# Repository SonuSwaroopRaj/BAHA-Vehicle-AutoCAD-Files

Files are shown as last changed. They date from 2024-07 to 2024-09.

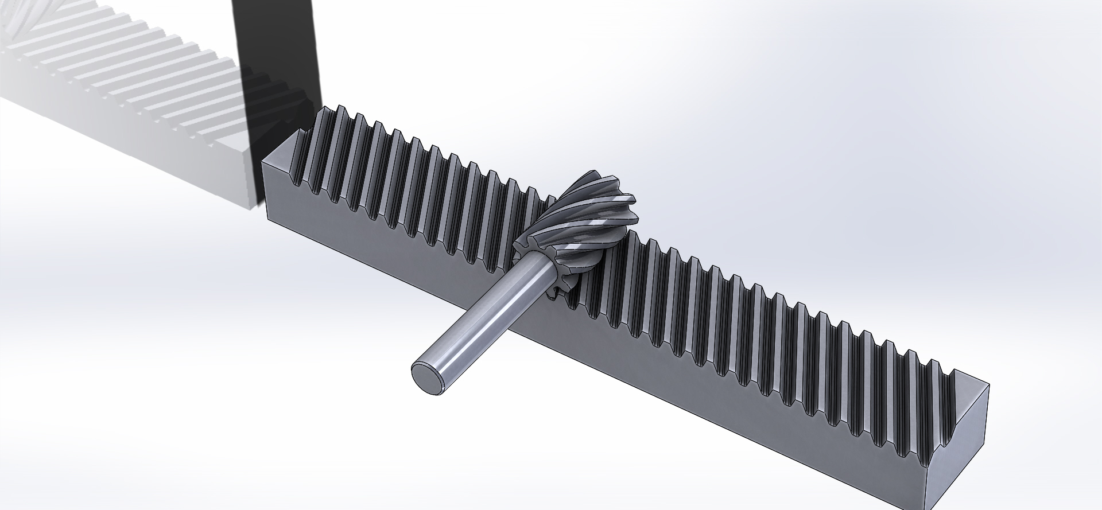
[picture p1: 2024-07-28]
RACK AND PINION DESIGN/RACK AND PINION.JPG

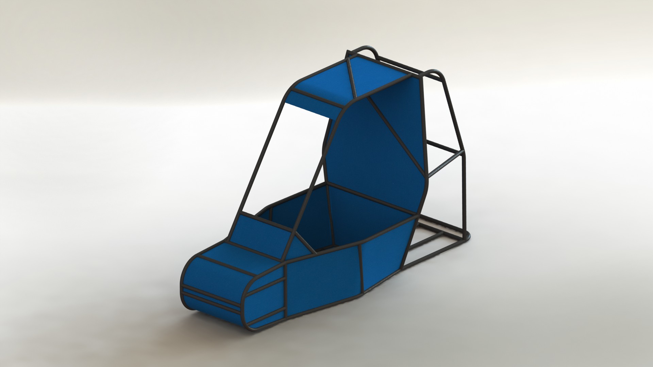
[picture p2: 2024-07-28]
ROLLCAGE CHASIS DESIGN/rendering 1420110908-19437-a36wyp.JPG

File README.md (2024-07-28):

# BAHA-Vehicle-AutoCAD-Files
This repository contains the AutoCAD files for our BAHA vehicle design. Here you'll find detailed schematics and 3D models related to the construction and design of our BAHA vehicle. The files are organized into relevant categories for easy navigation and reference. Contributions and updates to the designs are welcome.

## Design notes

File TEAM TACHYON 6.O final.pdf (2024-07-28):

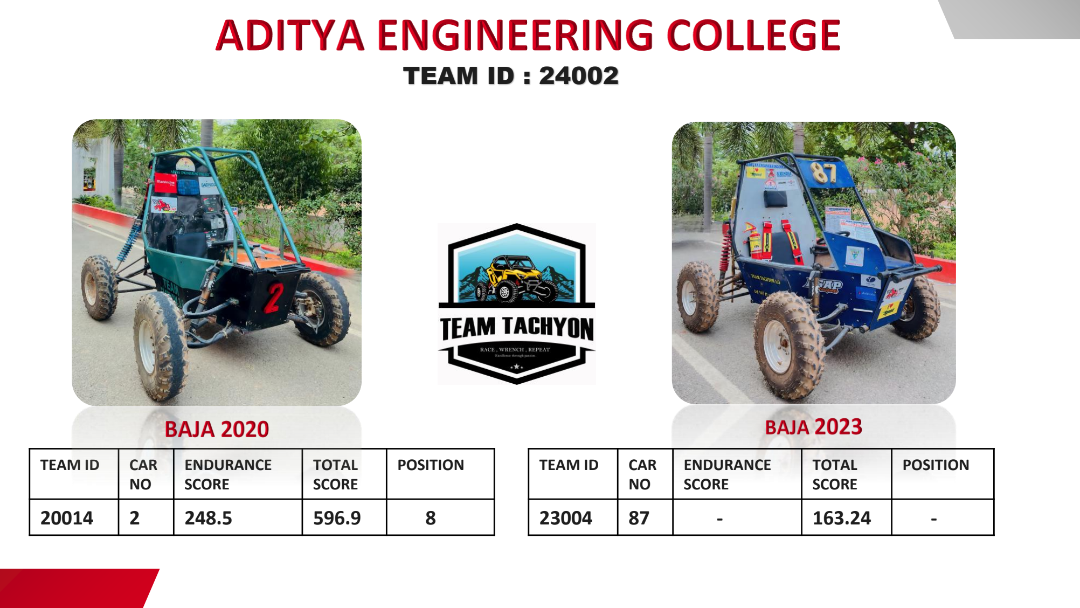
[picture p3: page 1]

TEAM ID : 24002

TEAM ID CAR
NO

ENDURANCE
SCORE

TOTAL
SCORE

POSITION

20014 | 2 | 248.5 | 596.9 | 8
TEAM ID | CAR
NO

ENDURANCE
SCORE

TOTAL
SCORE

POSITION

23004 | 87 | - | 163.24 | -

- No proper design for splash shield arrangement
- Issue in fixing the CVT and disk wheel casing
SUBSYSTEMS | FLAWS OF PREVIOUS VEHICLE | LESSONS LEARNT | IMPROVEMENT
ROLL CAGE | - | The front bracing member should have
| been the primary member but became secondary member
- No gusset between RHO & RRH
- Fbm should become
| | primary and continuous
- Should be available
| | gusset secondary according to rule book | FBM completely replaced with primary
SUSPENSION | - | Less camber control because of u arms | A-arms tend to offer more adjustability, To fine-tune the suspension settings for specific driving conditions.
- Damper position changed
to upper arm
- U- arms are replaced with A-arms
BRAKING | - | Less brake performance at rear wheels
- Occurance of brakages in hoses.
- Due to Y – split
- Because of non-
| | | metallic liners.
- Installing X- split braking circuit
- Using metallic brake liners STREERING - The ability to align the wheels not
accurtely
- No precise alignment | - Using sliding pair
TRANSMISSION | Less traction & limited torque distribution . | To required power to all 4
| | | wheels
- 4WD

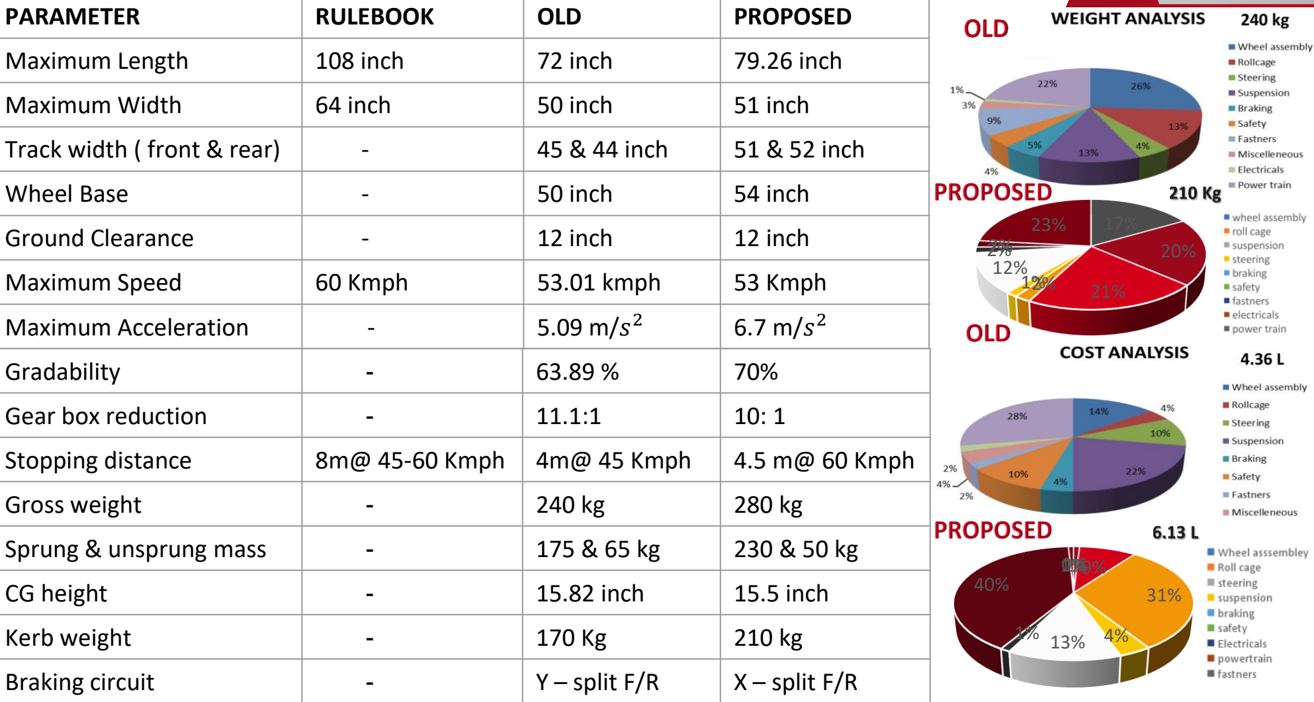
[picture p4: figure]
PARAMETER; RULEBOOK; OLD; PROPOSED; Maximum Length; 108 inch; 72 inch; 79.26 inch; Maximum Width; 64 inch; 50 inch; 51 inch; Wheel Base; 54 inch; Ground Clearance; 12 inch; Maximum Speed; 60 Kmph; 53.01 kmph; 53 Kmph; Maximum Acceleration; Gradability; Gear box reduction; Stopping distance; 8m@ 45-60 Kmph; 4m@ 45 Kmph; 4.5 m@ 60 Kmph; Gross weight; Sprung & unsprung mass; CG height; 15.82 inch; 15.5 inch; Kerb weight; Braking circuit; Y – split F/R; X – split F/R

Track width ( front & rear) | - | 45 & 44 inch | 51 & 52 inch

ROLL CAGE FEATURES

PARAMETER | VALUE | PARAMETER | ALLOWABLE VALUE | DESIGN VALUE
Total no.of joints | 94 | Maximum vehicle width | 64” | 50”
Total weld length | 5.9 m | Maximum vehicle length | 108” | 72”
Total tubing length | 50 m | Minimum firewall width of the RRH 27” above seat | > 29” | 30”
Roll cage weight | 41.3 kg
PARAMETER | OUTER DIA | THICKNESS
Primary pipes | 31.75 mm | 1.6 mm
Secondary pipes | 25.4 mm | 1.6 mm
Material used | Steel alloy with properties > 365 Mpa | AISI 4130
Vertical distance of SIM from seat (inches) | 8”- 14” | 12”
Fire wall angle | Max 20⁰ | 10⁰
Front bracing member angle | < 45 “ | 33.46”

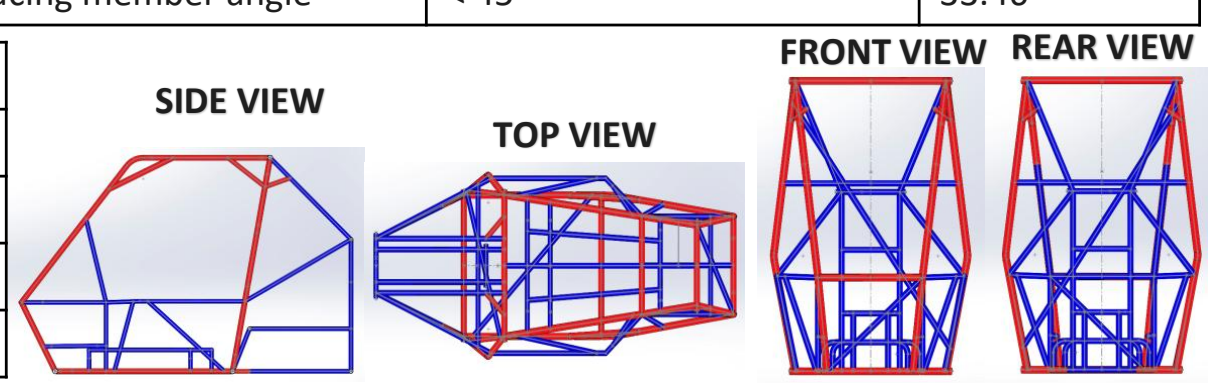
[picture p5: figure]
FRONT VIEW REAR VIEW; TOP VIEW; SIDE VIEW

PARAMETER | STD.VALUE | DESIGN VALUE
Elbows angle | 125⁰ - 140⁰ | 135⁰
Knee angle | 120⁰ - 150⁰ | 132⁰
Back angle | 8 0 - 15⁰ | 10⁰
Steering angle | 90⁰ - 65⁰ | 70⁰

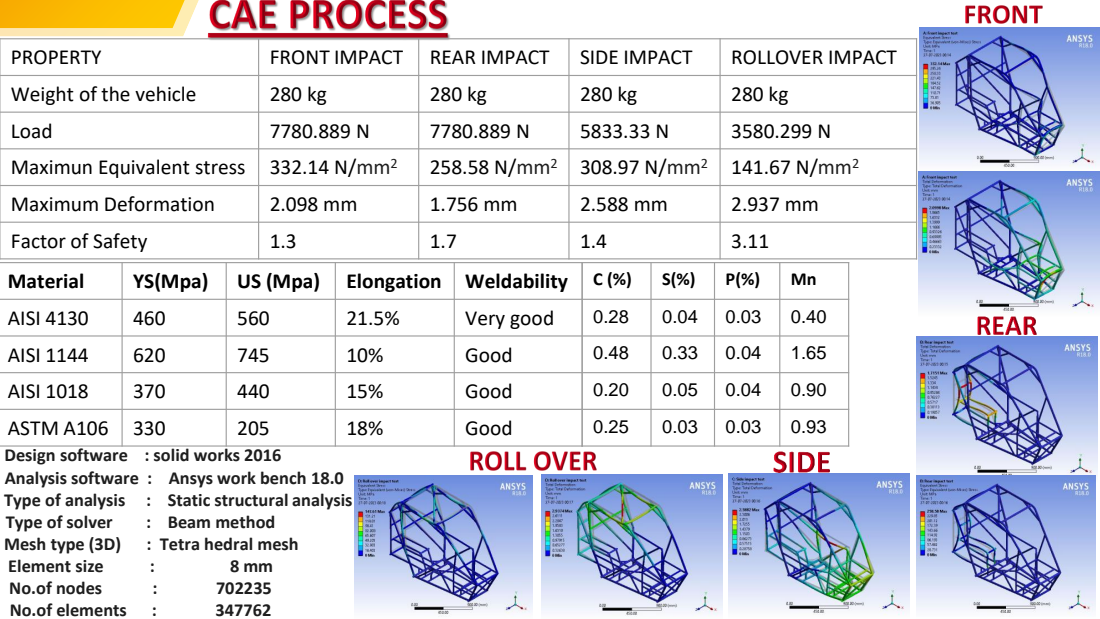
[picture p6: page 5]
Type of solver; : Beam method; Mesh type (3D); : Tetra hedral mesh; Element size; No.of nodes; No.of elements; Material; YS(Mpa); US (Mpa); Elongation; Weldability; AISI 4130; Very good; AISI 1144; Good; AISI 1018; ASTM A106; PROPERTY; FRONT IMPACT; REAR IMPACT; SIDE IMPACT; ROLLOVER IMPACT; Weight of the vehicle; Load; Maximun Equivalent stress; 332.14 N/mm²; 258.58 N/mm²; 308.97 N/mm²; 141.67 N/mm²; Maximum Deformation; Factor of Safety

Design software : solid works 2016
Analysis software : Ansys work bench 18.0
Type of analysis : Static structural analysis

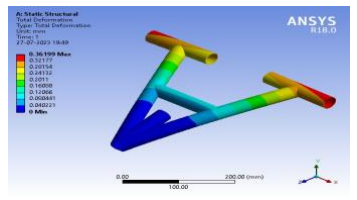
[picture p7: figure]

PARAMETER | FRONT | REAR
Suspension system | Double wish bone | H - arm
Natural frequency | 2.3 Hz | 2.5 Hz
Spring stifness | 6.942 N/mm | 16.147 N/mm
Roll rate | 19.315 Nm/deg | 22.28 Nm/deg
Suspension travel | Bump - 6” Droop - 4” | Bump – 4” Droop – 2”
Damper stroke | 5.8” | 6.2”
Damping force | 956.456 N | 1103.52 N
Damping coefficient | 2940.53 N.s/m | 3410.77 N.s/m
Damping ratio | 1.08 | 10.7
Wheel rate | 10”-6”bump,4”droop | 6” (4” bump,2” droop)
PARAMETER` | VALUE
CG height | 15.5’’
Ground clearance | 12”
Roll center height | FAW 12.52” RAW 12.49”
Motion ratios | FRONT -0.53 REAR - 1.33
Shock absorber | FOX FLOAT – 3EVOL
Helical
suspension

LINKAGE DESIGN

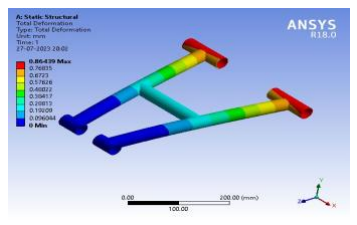
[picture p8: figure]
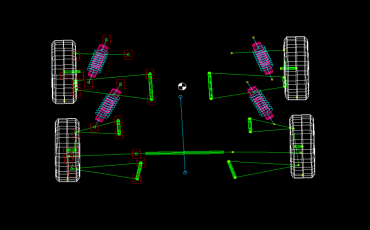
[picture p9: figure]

PARAMETER | FRONT | REAR
Camber | 2” | 2”
Caster | 2” | 0”
KPI | 8” | 0”
Scrub radius | 22 mm | 0 mm
TOE | 2 deg | 0 deg
MATERIAL | Chromium vanadium steel
Modulus of rigidity | 8000 mpa
Wire diameter | 9 mm
Eye to eye distance | 480 mm
No.of active coils | 15
Nominal diameter | 81 mm

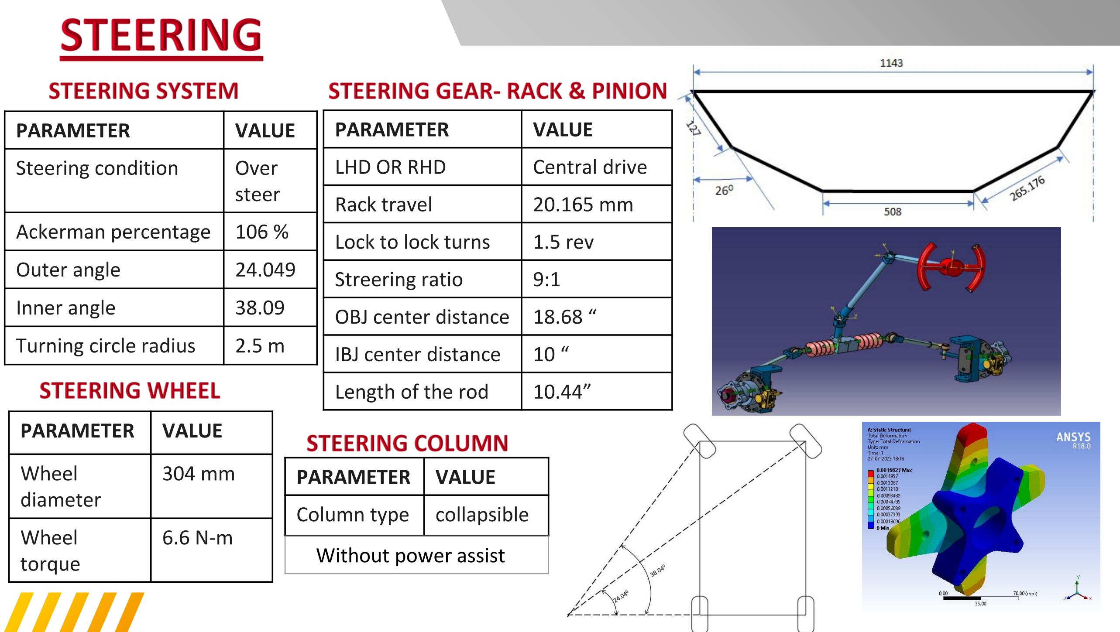
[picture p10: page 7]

PARAMETER | VALUE | PARAMETER | VALUE
Steering condition | Over steer | LHD OR RHD | Central drive
Rack travel | 20.165 mm
Lock to lock turns | 1.5 rev
Streering ratio | 9:1
OBJ center distance | 18.68 “
IBJ center distance | 10 “
Length of the rod | 10.44”
Ackerman percentage | 106 %
Outer angle | 24.049
Inner angle | 38.09
Turning circle radius | 2.5 m
PARAMETER | VALUE

Wheel
diameter

304 mm

Wheel
torque

6.6 N-m

PARAMETER | VALUE
Column type | collapsible

Without power assist

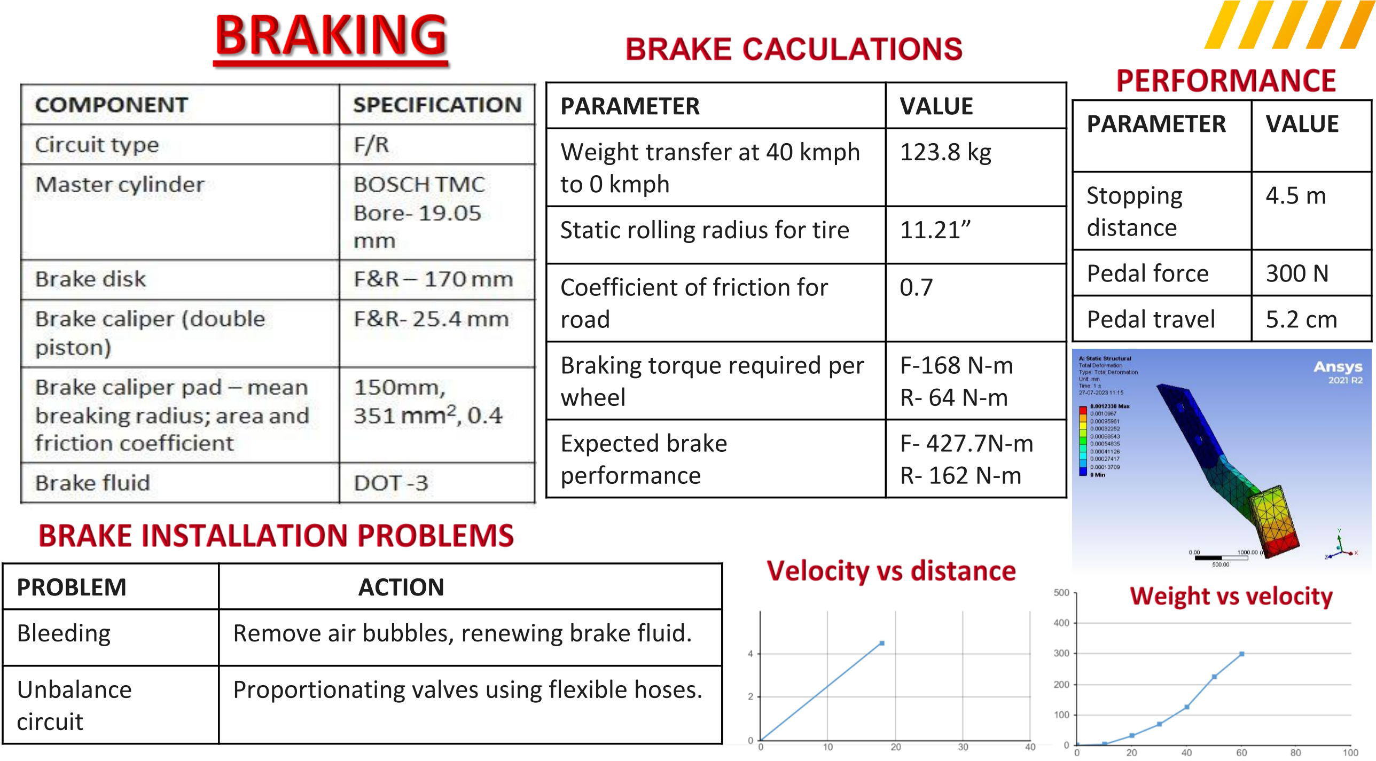
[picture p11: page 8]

PARAMETER | VALUE
Weight transfer at 40 kmph to 0 kmph | 123.8 kg
Static rolling radius for tire | 11.21”
Coefficient of friction for road | 0.7
Braking torque required per wheel | F-168 N-m R- 64 N-m
Expected brake performance | F- 427.7N-m R- 162 N-m
PARAMETER | VALUE
Stopping distance | 4.5 m
Pedal force | 300 N
Pedal travel | 5.2 cm
PROBLEM | ACTION
Bleeding | Remove air bubbles, renewing brake fluid.
Unbalance circuit | Proportionating valves using flexible hoses.

BRIGGS & STRATTON 10 HP
OHV – VANGUARD MODEL 20
PARAMETER | VALUE
Max. diameter | 189.36 mm
Min. diameter | 180.03 mm
Pulley center distance | 257 mm
Length of the belt | 927 mm
Pulley groove angle | 32 deg
Max. power | 7.457 KW
Max . torque | 18.75 N-m
PARAMETER` | VALUE
Gear train | Double compound Gear train
Gear Reduction ratios | 10: 1
Casing material | Aluminium alloy 6065
Gear material | EN 19
Engine : CVT : Gearbox | 18.75:3: 10:1

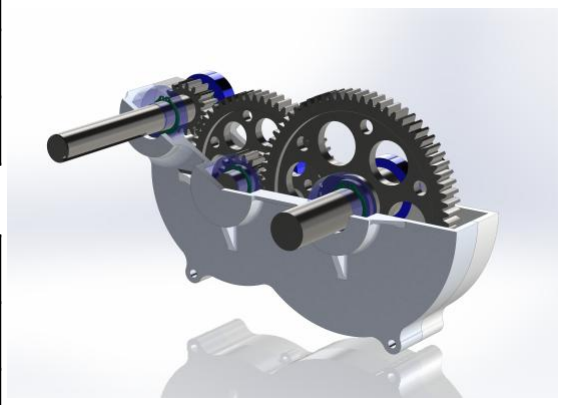
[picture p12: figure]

PARAMETER | VALUE
Maximun speed | 53 Kmph
Acceleration | 6.7 m/s
Gradeability | 70 %
Vehicle required torque | 780 N-m
Diameter | 23 inch
Width | 7 inch
Height | 10 inch

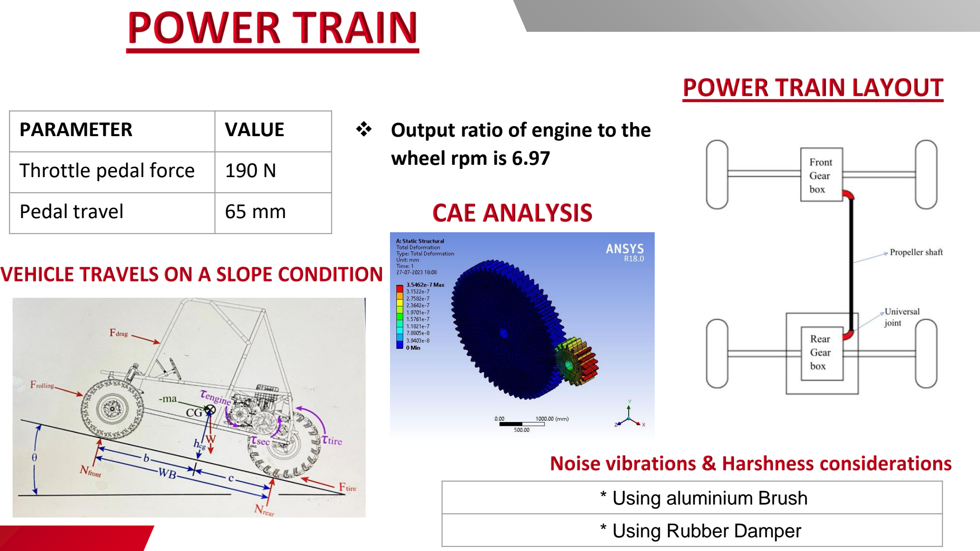
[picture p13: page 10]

* Using aluminium Brush

* Using Rubber Damper

PARAMETER | VALUE
Throttle pedal force | 190 N
Pedal travel | 65 mm

❖ Output ratio of engine to the wheel rpm is 6.97

0

09-05-23 | 08-06-23 | 08-07-23 | 07-08-23 | 06-09-23 | 06-10-23 | 05-11-23 | 05-12-23 | 04-01-24
WrittenTest
Interview
Team finalization
Team registration
Subsystem division
Study of old vehicle
Data acquisition
CAD analysis
Subsystem calculations
CAD analysis
Preliminary round preparation Preliminary Round
Modification and analysis
Material procurement
Manufacturing & Machining & Assembly Virtual event preparation
Virtual Static and Dynamic Rounds Vehicle testing & repairs
Physical Dynamic Event preparation Physical Dynamic Event

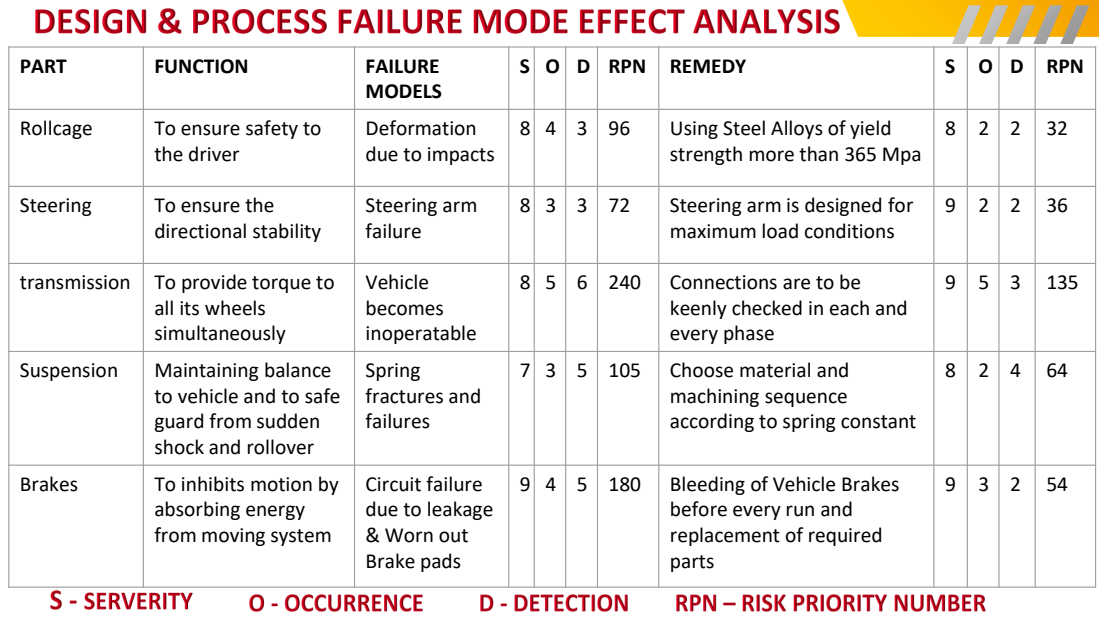
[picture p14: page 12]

PART | FUNCTION | FAILURE MODELS | S | O | D | RPN | REMEDY | S | O | D | RPN

Rollcage | To ensure safety to the driver | Deformation due to impacts | 8 | 4 | 3 | 96 | Using Steel Alloys of yield strength more than 365 Mpa | 8 | 2 | 2 | 32

Steering | To ensure the directional stability | Steering arm failure | 8 | 3 | 3 | 72 | Steering arm is designed for maximum load conditions | 9 | 2 | 2 | 36

transmission | To provide torque to all its wheels simultaneously | Vehicle becomes inoperatable | 8 | 5 | 6 | 240 | Connections are to be keenly checked in each and every phase | 9 | 5 | 3 | 135

Suspension | Maintaining balance to vehicle and to safe guard from sudden shock and rollover | Spring fractures and failures | 7 | 3 | 5 | 105 | Choose material and machining sequence according to spring constant | 8 | 2 | 4 | 64

Brakes | To inhibits motion by absorbing energy from moving system | Circuit failure due to leakage & Worn out Brake pads | 9 | 4 | 5 | 180 | Bleeding of Vehicle Brakes before every run and replacement of required parts | 9 | 3 | 2 | 54

SYSTEM | PARAMETER | CHECKING METHODOLOGY | DESIGN VALUE
ROLLCAGE | Sustainability crashes | Using ANSYS software | FOS : 2
SUSPENSION | Wheel Travel | Vehicle is lifted by using jack, wheel is removed and hub travel is noted with respect to center position. | Bump : 6 inch Droop : 4 inch
STEERING | Turning Radius | To be tested in the figure of:- 8 | Based on physical performance
POWER TRAIN | Top Speed | Vehicle is driven at full throttle up to a distance of 200ft and note the speed and also time taken to cover the distance is noted using sensors | Based on physical performance
BRAKING | Stopping distance | Driver starts braking at minimum speed (45kmph) while crossing a reference line. Maximum force is applied on the brake pedal, there by checking all wheels lock simultaneously or not and distance is measured from the line to the front tires. | Based on physical performance

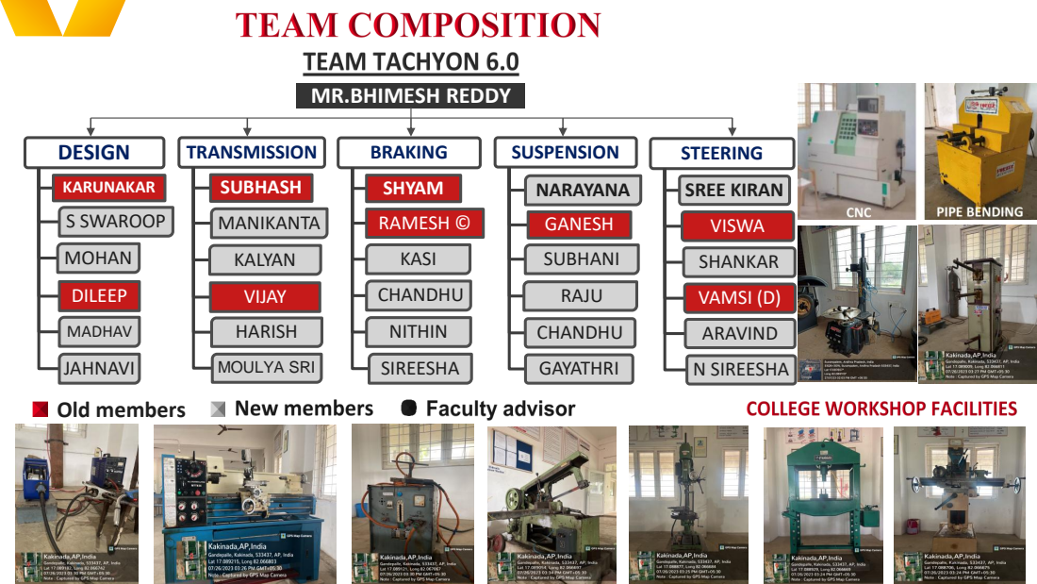
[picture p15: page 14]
DESIGN; KARUNAKAR; S SWAROOP; MOHAN; DILEEP; MADHAV; JAHNAVI; TRANSMISSION; SUBHASH; MANIKANTA; KALYAN; VIJAY; HARISH; MOULYA SRI; BRAKING; SHYAM; RAMESH ©; KASI; CHANDHU; NITHIN; SIREESHA; SUSPENSION; NARAYANA; GANESH; SUBHANI; RAJU; GAYATHRI; STEERING; SREE KIRAN; VISWA; SHANKAR; VAMSI (D); ARAVIND; N SIREESHA; Old members

MR.BHIMESH REDDY

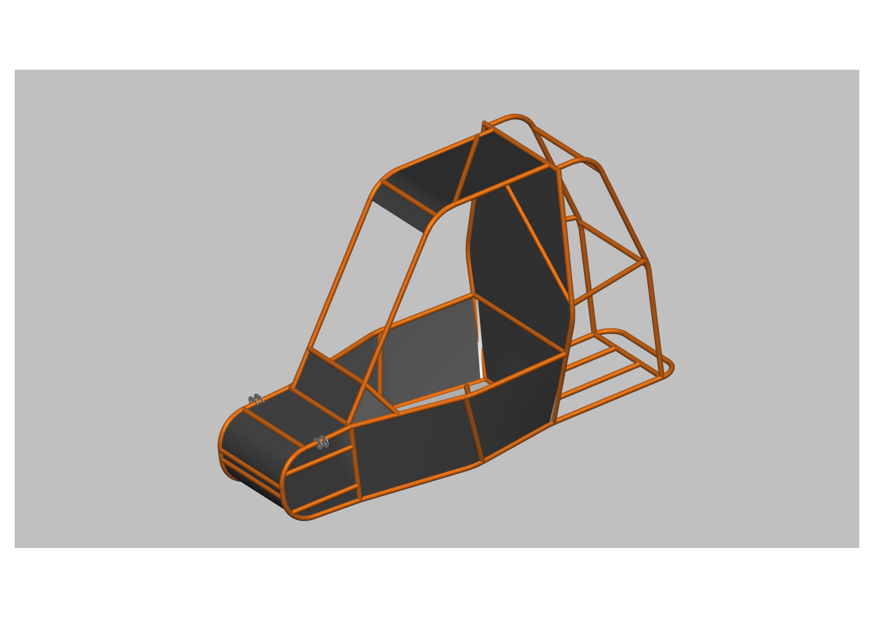
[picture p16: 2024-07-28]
ROLLCAGE CHASIS DESIGN/Rollcage_PDF 1_page-0001.jpg

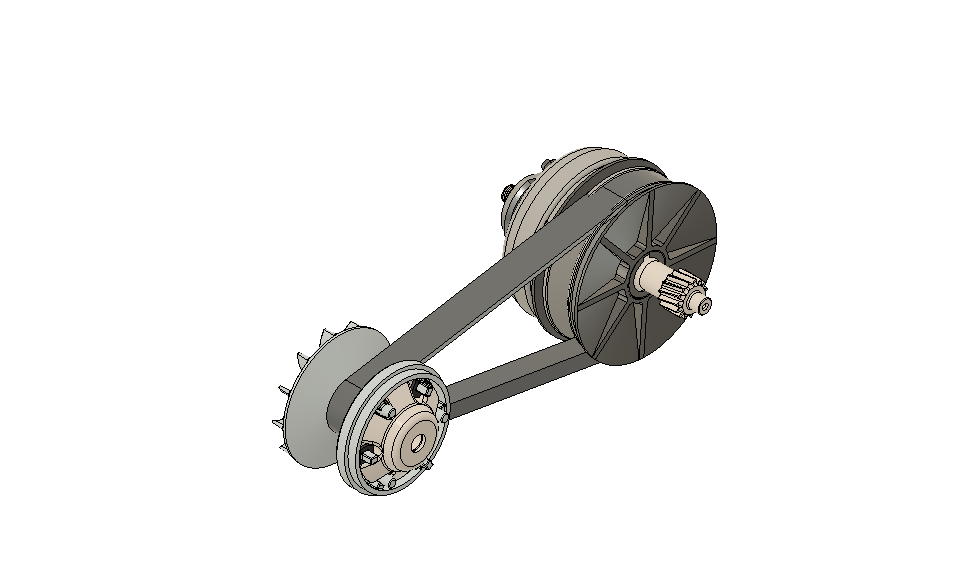
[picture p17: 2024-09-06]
CVT Design/CVT.00.png

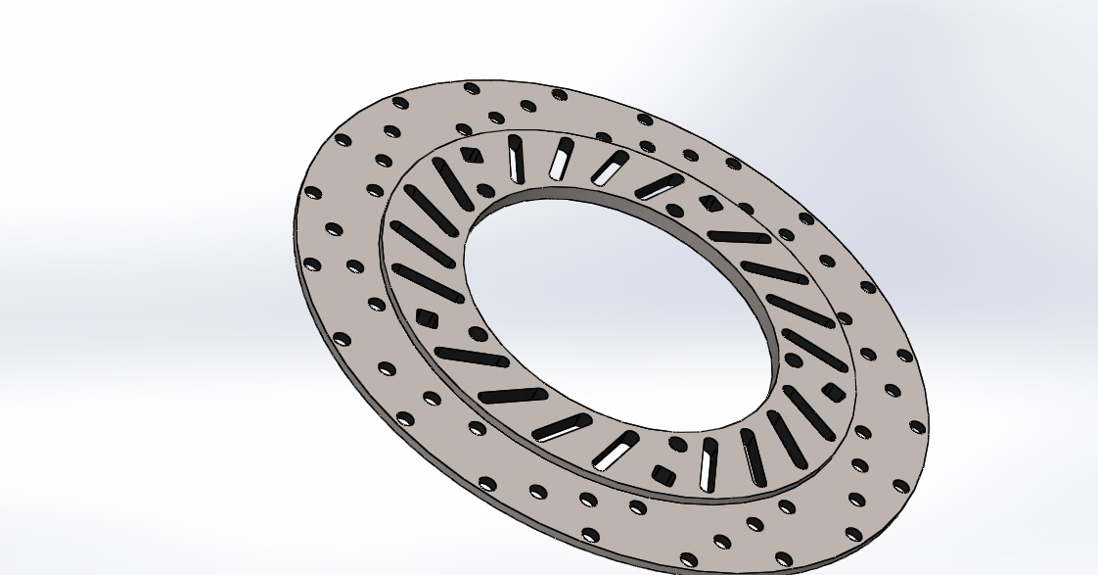
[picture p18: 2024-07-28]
BRAKE DESIGN/BRAKE 1/DISK BRAKE2.JPG

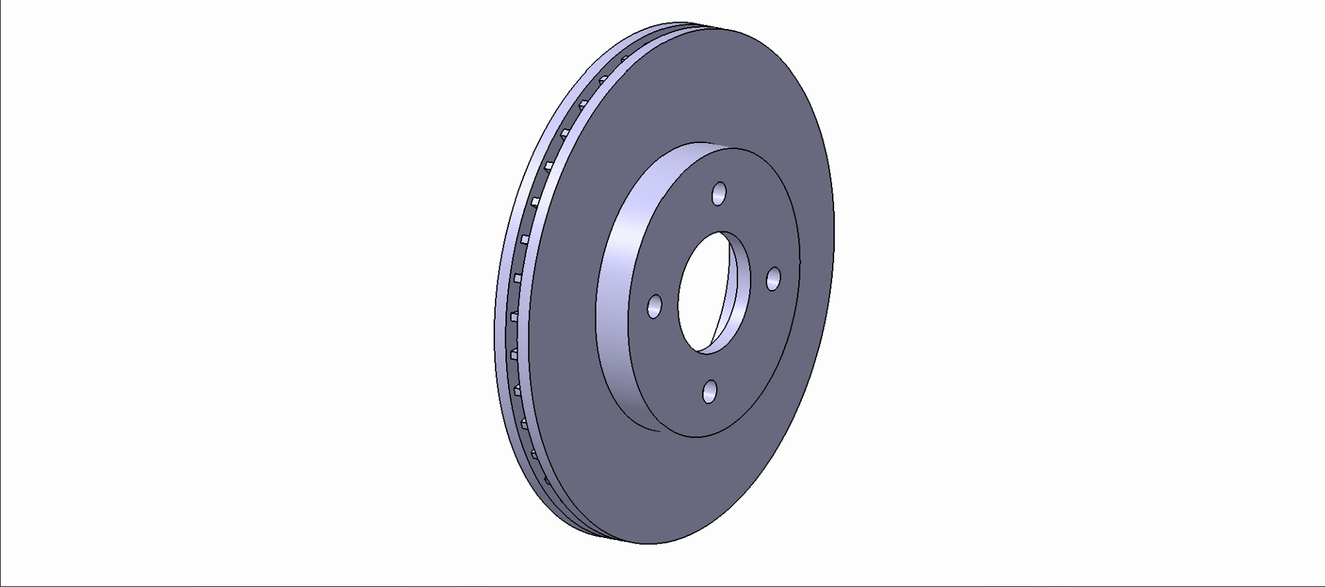
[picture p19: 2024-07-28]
BRAKE DESIGN/BRAKE 2/View (1).png

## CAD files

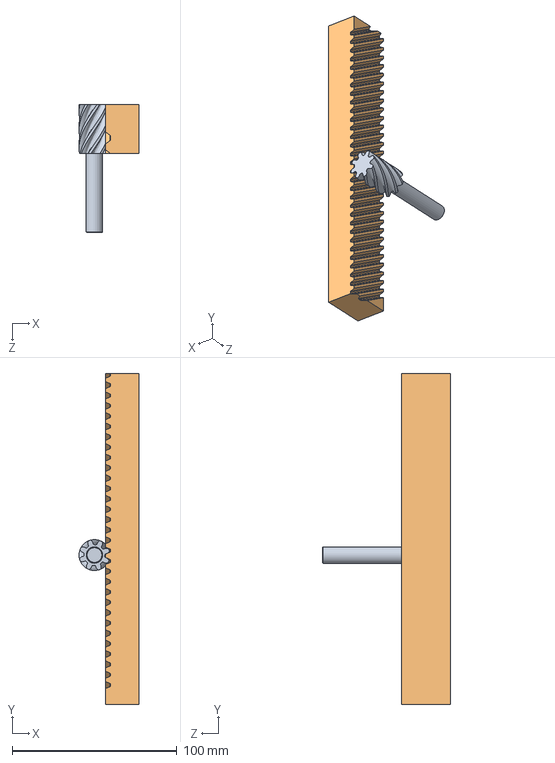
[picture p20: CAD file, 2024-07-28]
RACK AND PINION DESIGN/RACK AND PINION.SLDASM
36.4 x 201.1 x 78.0 mm
PINION
RACK

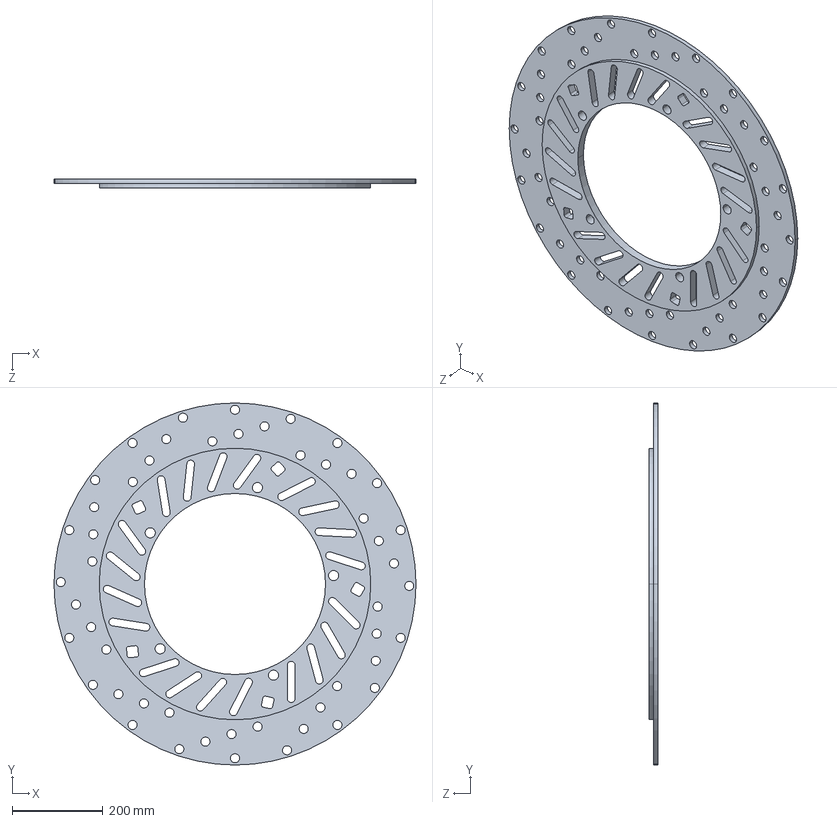
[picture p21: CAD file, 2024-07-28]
BRAKE DESIGN/BRAKE 1/DISK BRAKE.STEP
800.0 x 800.0 x 20.0 mm

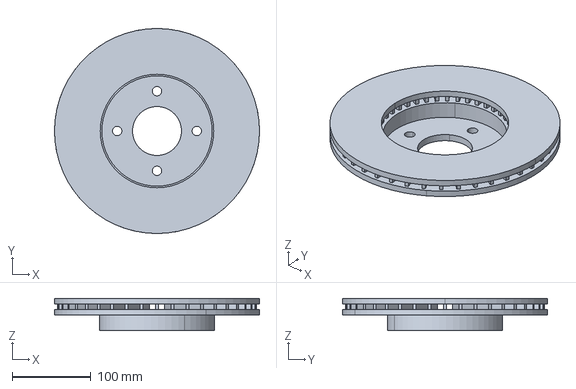
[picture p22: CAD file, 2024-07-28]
BRAKE DESIGN/BRAKE 2/Part3.igs
260.0 x 260.0 x 41.0 mm

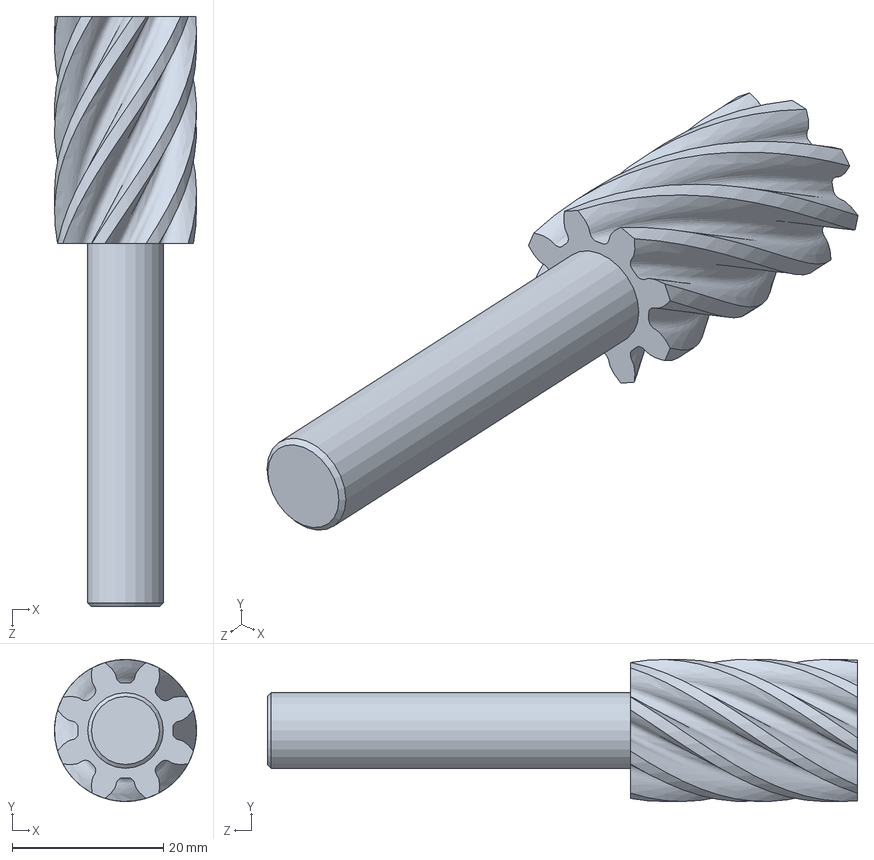
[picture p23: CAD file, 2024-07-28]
RACK AND PINION DESIGN/PINION.SLDPRT
18.8 x 18.8 x 78.0 mm

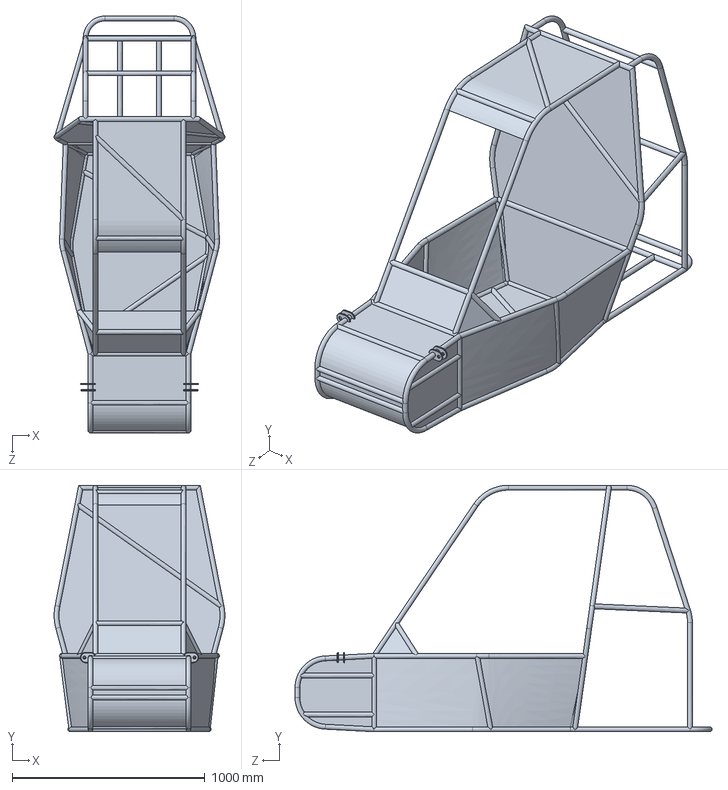
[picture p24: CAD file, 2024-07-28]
ROLLCAGE CHASIS DESIGN/Rollcage.SLDPRT
885.6 x 1278.3 x 2162.7 mm

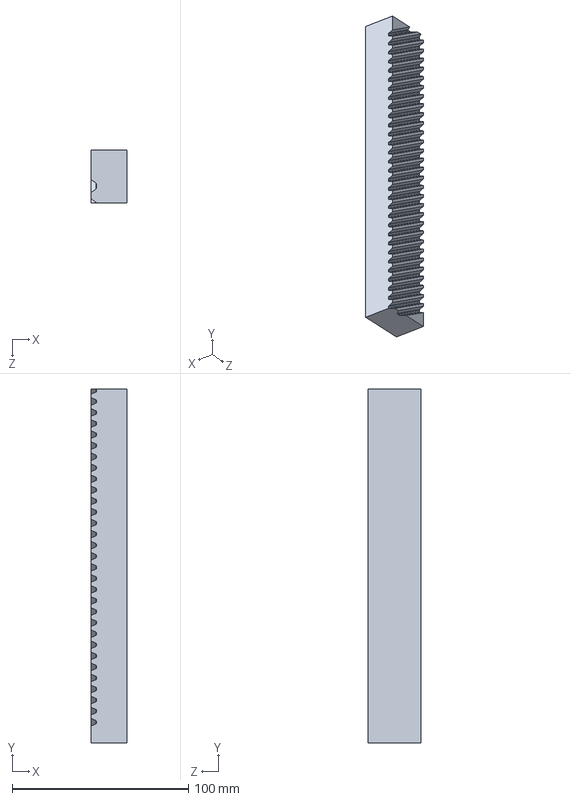
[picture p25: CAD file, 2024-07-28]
RACK AND PINION DESIGN/RACK.SLDPRT
20.4 x 201.1 x 30.0 mm

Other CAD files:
BRAKE DESIGN/BRAKE 1/DISK BRAKE.SLDPRT
BRAKE DESIGN/BRAKE 2/Part3.CATPart
